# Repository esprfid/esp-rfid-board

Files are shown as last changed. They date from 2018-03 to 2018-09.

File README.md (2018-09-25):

# ESP12 / ESP12F / ESP12E / ESP12S Wiegand rfid board

Small ESP12F breakout board, custom built for Wiegand RFID readers.

### You can get this board from my Tindie shop:
<a href="https://www.tindie.com/stores/nardev/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">

</a>

WARNING: Although it’s rated for more than 12V, i strongly suggest to use maximum of 12V input!

Check the image for explanation of how to hook up the reader

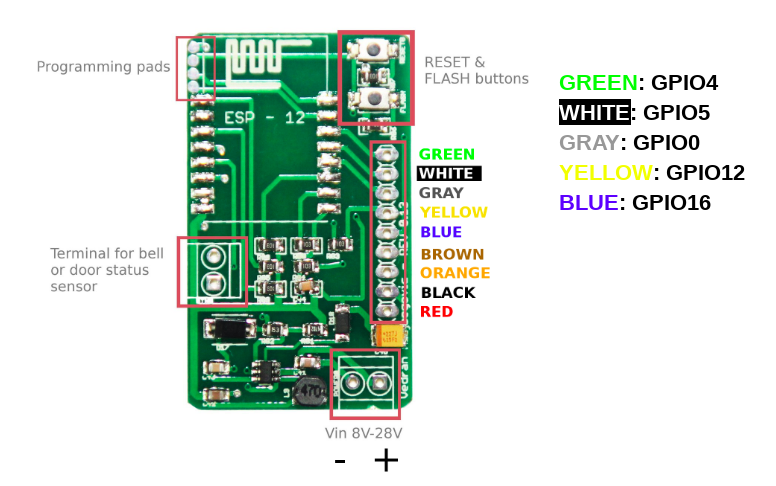
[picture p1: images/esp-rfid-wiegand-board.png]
&nbsp;&nbsp;

** There is a resistor on the way from ESP to buzzer due to strange behaviour of busser that ditn't react to HIGN/LOW except if there is a resitor on the way from ESP to Wiegand reader.

Custom pads

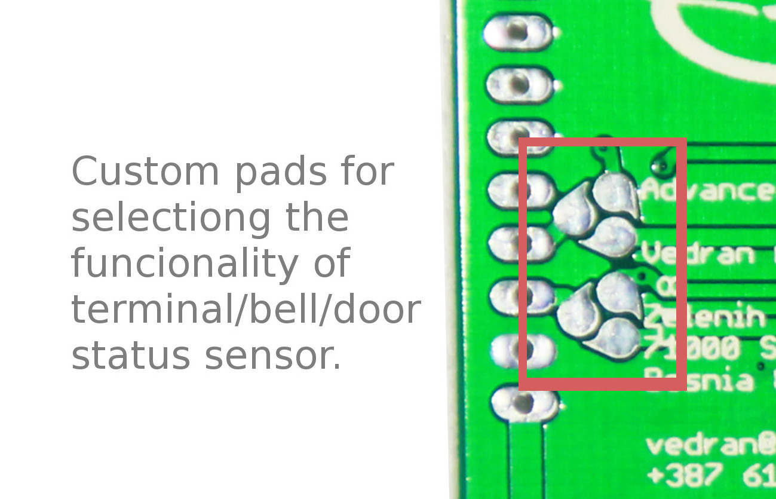
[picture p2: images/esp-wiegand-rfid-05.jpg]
&nbsp;&nbsp;
<br>
** New board has marked pads

**Option 1:**
Solder 2 and 1 on both pads results in passing “Ring” tactile switch/button to ESP8266 pin GPIO14

**Option 2:**
Solder 3 and 2 on both pads results in passing “Ring” switch to a terminal on  another side of board.

**Option 3:**
Solder 1 and 3 on both pads results in passing terminal pins to ESP8266 GPIO14, planned so that you can hook door status magnet sensor. In this case, you can’t use “Ring” button in Option 1. or 2.

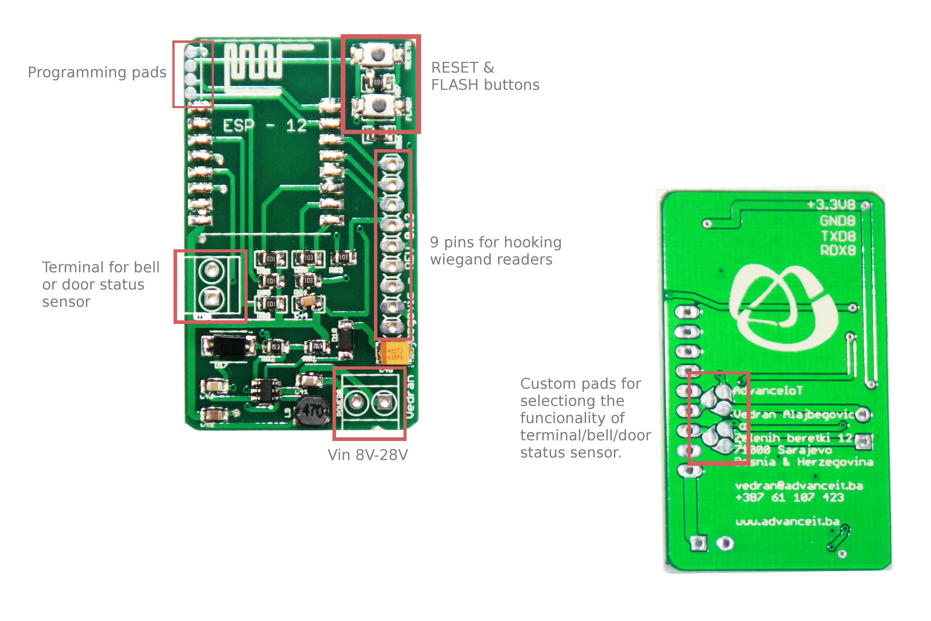
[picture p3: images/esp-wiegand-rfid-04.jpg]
&nbsp;&nbsp;

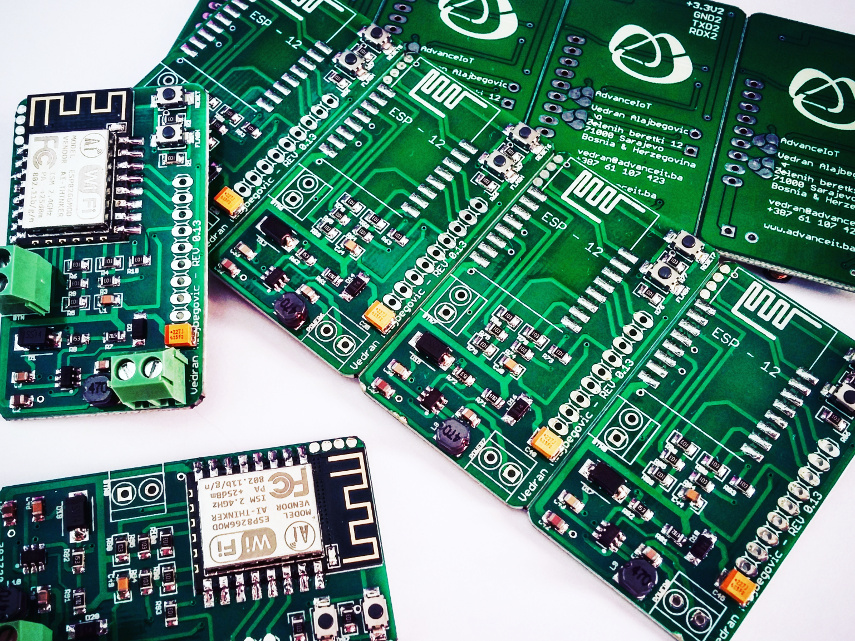
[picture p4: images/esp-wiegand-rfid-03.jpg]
&nbsp;&nbsp;
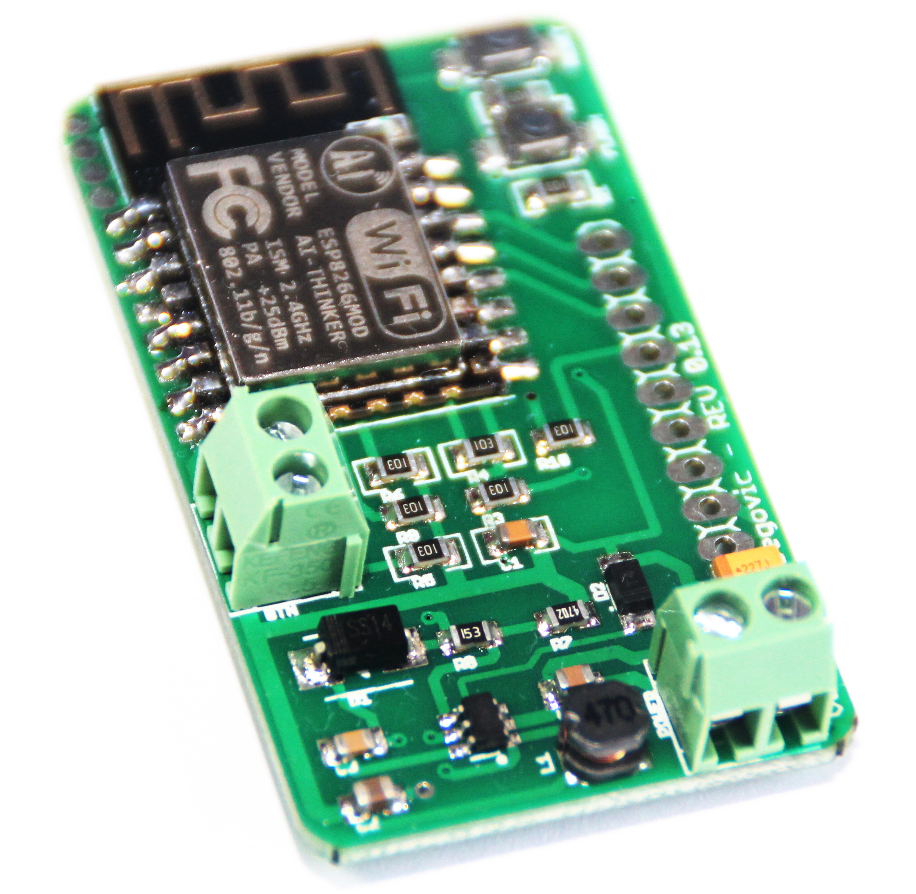
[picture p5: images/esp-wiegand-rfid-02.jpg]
&nbsp;&nbsp;
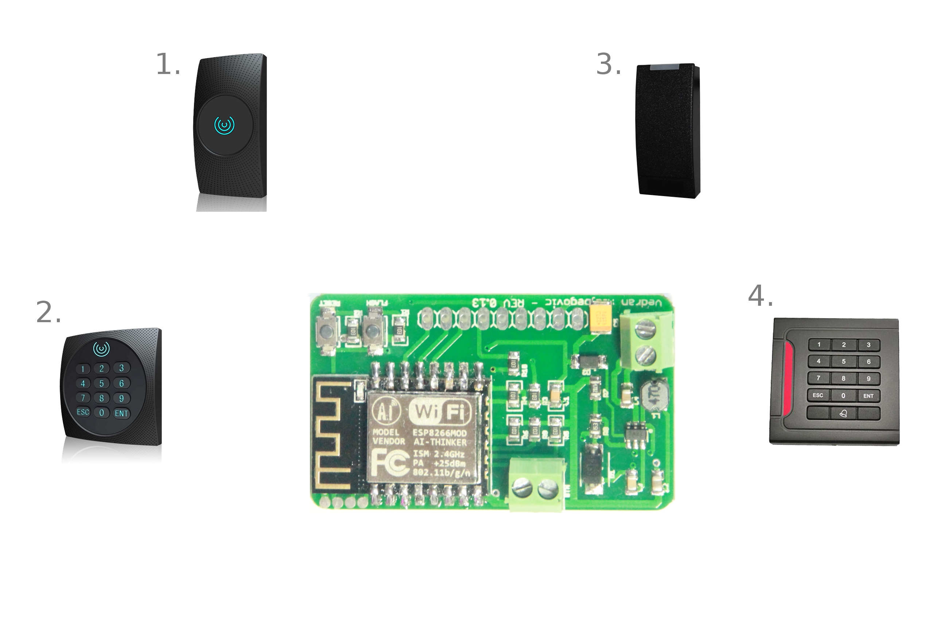
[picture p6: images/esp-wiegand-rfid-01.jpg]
&nbsp;&nbsp;

* BOM has some mistakes, contact me if you need some help.

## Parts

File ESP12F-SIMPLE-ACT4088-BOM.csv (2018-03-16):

Part | Value | Device | Package | Description
BTN | GTN | SCREW-TERMINAL-GREEN(2P-3.5) | H2-3.5-7.0X7.0MM | 320110028
BUCKCONV | AIC1896CG-SOT23-6 | ACT4088-(SOT23-6) | SOT-23-6 | 310030104
C1 | 100n | CAPC0805 | C_0805
C2 | 22uF | C-EUC0805K | C0805K | CAPACITOR, European symbol
C3 | 22nF | C-EUC0805K | C0805K | CAPACITOR, European symbol
C4 | 10uF | C-EUC0805K | C0805K | CAPACITOR, European symbol
C5 | 220uF | CAPC1411 | 1411/3528 | CAPACITOR 6.3V/220UF
D1 |  | SCHOTTKY-DIODESMD | SMB | Schottky Diode
D2 | LL4148 | LL4148 | SOD80_DO213AA_MINIMELF | 1N4148 General Purpose Rectifie
F1 |  | SJ2W | SJ_2 | SMD solder JUMPER
F2 |  | SJ2W | SJ_2 | SMD solder JUMPER
L1 | 4.7uH | L-EUL3225M | L3225M | INDUCTOR, European symbol
PINOUT |  | PINHD-1X9 | 1X09 | PIN HEADER
POWER | BTN | SCREW-TERMINAL-GREEN(2P-3.5) | H2-3.5-7.0X7.0MM | 320110028
R1 | 10K | RESISTORR0805 | R_0805
R2 | 10K | RESISTORR0805 | R_0805
R3 | 10K | R-EU_R0805 | R0805 | RESISTOR, European symbol
R4 | 10K | RESISTORR0805 | R_0805
R5 | 10K | RESISTORR0805 | R_0805
R6 | 10K | RESISTORR0805 | R_0805
R7 | 49.9K | R-EU_R0805 | R0805 | RESISTOR, European symbol
R8 | 16.2K | R-EU_R0805 | R0805 | RESISTOR, European symbol
R9 | 10K | R-EU_R0805 | R0805 | RESISTOR, European symbol
R10 | 10K | R-EU_R0805 | R0805 | RESISTOR, European symbol
RESET |  | BUTTON-2PSWITCH-TURTLE-2P | 2P-SWITCH-TURTLE
SW1 | FLASH | BUTTON-2PSWITCH-TURTLE-2P | 2P-SWITCH-TURTLE
TP1 | TPTP15R | TPTP15R | TP15R | Test pad
TP2 | TPTP15R | TPTP15R | TP15R | Test pad
TP3 | TPTP15R | TPTP15R | TP15R | Test pad
TP4 | TPTP15R | TPTP15R | TP15R | Test pad
U1 |  | ESP12SMD | ESP12-SMD | ESP8266 Wifi module 12

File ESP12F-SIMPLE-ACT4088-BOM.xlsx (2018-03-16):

NUMBER | Part | Value | Device | Package | Description
1 | BTN |  | SCREW-TERMINAL-GREEN(2P-3.5) | H2-3.5-7.0X7.0MM
1 | BUCKCONV | AIC1896CG-SOT23-6 | ACT4088-(SOT23-6) | SOT23-6 | I think that you can get those at: https://world.tmall.com/item/525197822499.htm?id=525197822499&ns=1&abbucket=18
1 | C1 | 100n | CAPC0805 | C0805K
2 | C2 | 22uF | CAPC0805 | C0805K | CAPACITOR, European symbol
x | C3 | 22nF | CAPC0805 | C0805K | CAPACITOR, European symbol
1 | C4 | 10uF | CAPC0805 | C0805K | CAPACITOR, European symbol
 | C5 | 220uF | CAPC1411 | 1411/3528 | CAPACITOR 6.3V/220UF
1 | D1 |  | SCHOTTKY-DIODESMD-SSB44-E3/52T | SMB | Schottky Diode, this one or similar: https://world.taobao.com/item/530833486252.htm?spm=a312a.7700714.0.0.7df3e12cR9cpXS#detail
1 | D2 | LL4148 | 1N4148 | SOD80_DO213AA_MINIMELF | 1N4148 General Purpose Rectifie, If you can’t get this one, you can skip it for demo board. I don’t know if this one is right size: https://world.tmall.com/item/14037506268.htm?id=14037506268&ali_trackid=1_09a98b3ccd918b57bda5394b2578982a
 | F1 |  | SJ2W | SJ_2 | SMD solder JUMPER
 | F2 |  | SJ2W | SJ_2 | SMD solder JUMPER
1 | L1 | 4.7uH | L-EUL3225M | L3225M | Inductor OR SAME VALUE, SAME PADS another one… Maybe this one: https://world.tmall.com/item/558066240065.htm?spm=a312a.7700714.0.0.2c8e0dba3eIeay
 | PINOUT |  | PINHD-1X9 | 1X09 | PIN HEADER
1 | POWER |  | SCREW-TERMINAL-GREEN(2P-3.5) | H2-3.5-7.0X7.0MM
8 | R1 | 10K | RESISTORR0805 | R0805
x | R2 | 10K | RESISTORR0805 | R0805
x | R3 | 10K | RESISTORR0805 | R0805
x | R4 | 10K | RESISTORR0805 | R0805
x | R5 | 10K | RESISTORR0805 | R0805
x | R6 | 10K | RESISTORR0805 | R0805
1 | R7 | 49.9K | RESISTORR0805 | R0805 | RESISTOR, European symbol
1 | R8 | 16.2K | RESISTORR0805 | R0805 | RESISTOR, European symbol
x | R9 | 10K | RESISTORR0805 | R0805 | RESISTOR, European symbol
x | R10 | 10K | RESISTORR0805 | R0805 | RESISTOR, European symbol
2 | RESET | RESET | BUTTON-2PSWITCH-TURTLE-2P | 2P-SWITCH-TURTLE
x | FLASH | FLASH | BUTTON-2PSWITCH-TURTLE-2P | 2P-SWITCH-TURTLE
 | GND | TPTP15R | TPTP15R | TP15R | Test pad
 | TXD | TPTP15R | TPTP15R | TP15R | Test pad
 | RXD | TPTP15R | TPTP15R | TP15R | Test pad
 | +3.3V | TPTP15R | TPTP15R | TP15R | Test pad
1 | MCU |  | ESP12SMD | ESP12-SMD | ESP12F - 8266 Wifi module 12
11
2 |  | SKIP PARTS WITH THIS BACKGROUND COLOR
13 |  | Read the description

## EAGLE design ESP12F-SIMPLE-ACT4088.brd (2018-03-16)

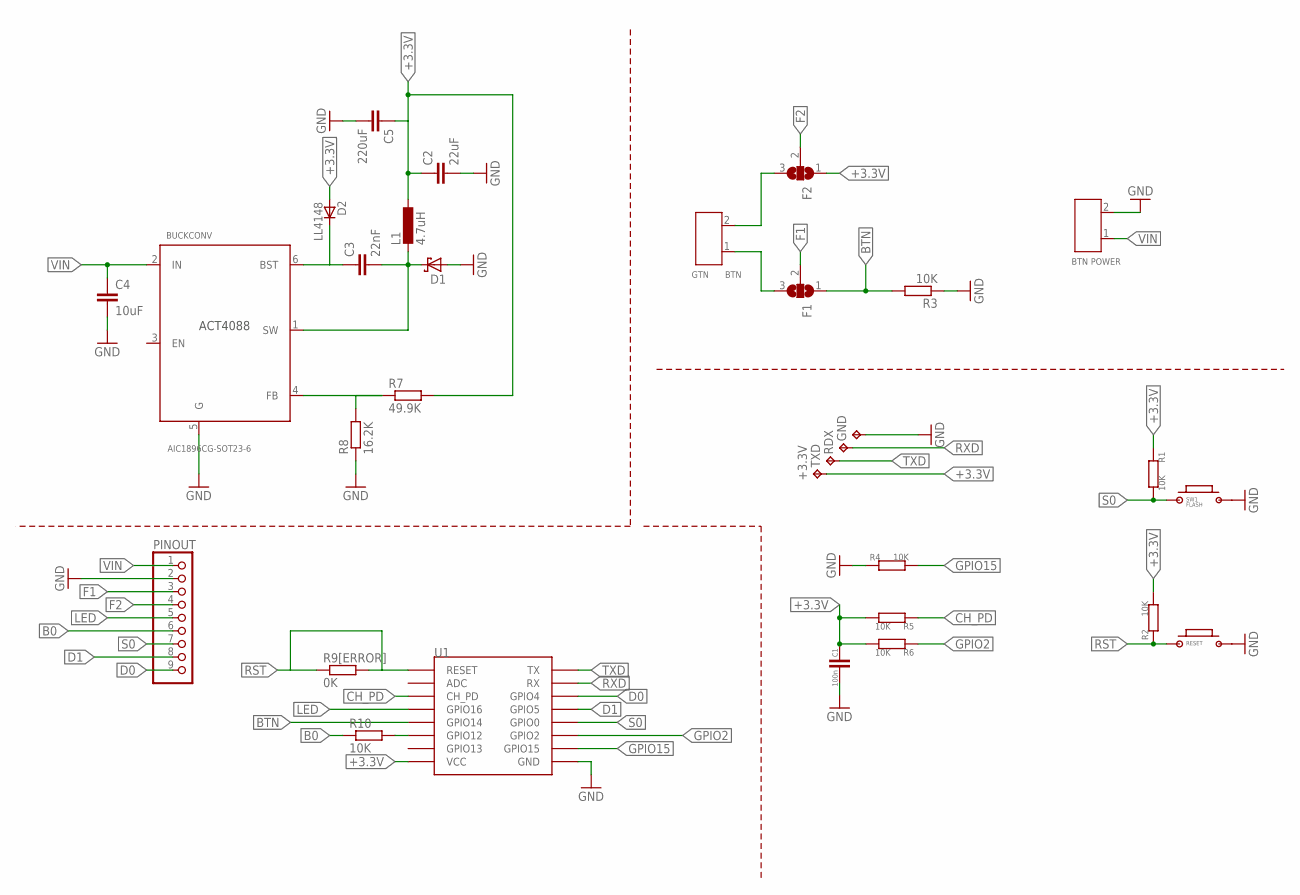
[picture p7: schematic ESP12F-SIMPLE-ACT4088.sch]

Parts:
+3.3V: TPTP15R; TP15R
BTN: GTN; H2-3.5-7.0X7.0MM
BUCKCONV: AIC1896CG-SOT23-6; SOT-23-6
C1: 100n; C_0805
C2: 22uF; C0805K
C3: 22nF; C0805K
C4: 10uF; C0805K
C5: 220uF; C1210
D1: SCHOTTKY-DIODESMD; SMB
D2: LL4148; SOD80_DO213AA_MINIMELF
F1, F2: SJ2WX; SJ_2XX
GND: TPTP15R; TP15R
L1: 4.7uH; L3225M
PINOUT: PINHD-1X9; 1X09
POWER: BTN; H2-3.5-7.0X7.0MM
R1, R2, R4, R5, R6: 10K; R_0805
R3, R10: 10K; R0805
R7: 49.9K; R0805
R8: 16.2K; R0805
R9[ERROR]: 0K; R0805
RDX: TPTP15R; TP15R
RESET: BUTTON-2PSWITCH-TURTLE-2P; 2P-SWITCH-TURTLE
SW1: FLASH; 2P-SWITCH-TURTLE
TXD: TPTP15R; TP15R
U1: ESP12SMD; ESP12-SMD

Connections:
+3.3V: +3.3V.TP, C1.1, C2.1, C5.1, D2.A, F2.1, L1.1, R1.1, R2.2, R5.2, R6.2, R7.2, U1.VCC
B0: PINOUT.6, R10.1
BTN: F1.1, R3.2, U1.GPIO14
CH_PD: R5.1, U1.CH_PD
D0: PINOUT.9, U1.GPIO4
D1: PINOUT.8, U1.GPIO5
F1: F1.2, PINOUT.3
F2: F2.2, PINOUT.4
GND: BUCKCONV.5 (G), C1.2, C2.2, C4.2, C5.2, D1.A, GND.TP, PINOUT.2, POWER.2, R3.1, R4.1, R8.1, RESET.2, SW1.2, U1.GND
GPIO2: R6.1, U1.GPIO2
GPIO15: R4.2, U1.GPIO15
LED: PINOUT.5, U1.GPIO16
unnamed: BUCKCONV.1 (SW), C3.2, D1.C, L1.2
unnamed: R10.2, U1.GPIO12
unnamed: BUCKCONV.6 (BST), C3.1, D2.C
unnamed: BUCKCONV.4 (FB), R7.1, R8.2
unnamed: BTN.1, F1.3
unnamed: BTN.2, F2.3
RST: R2.1, R9[ERROR].1, R9[ERROR].2, RESET.1, U1.RESET
RXD: RDX.TP, U1.RXD0 (RX)
S0: PINOUT.7, R1.2, SW1.1, U1.GPIO0
TXD: TXD.TP, U1.TXD0 (TX)
VIN: BUCKCONV.2 (IN), C4.1, PINOUT.1, POWER.1

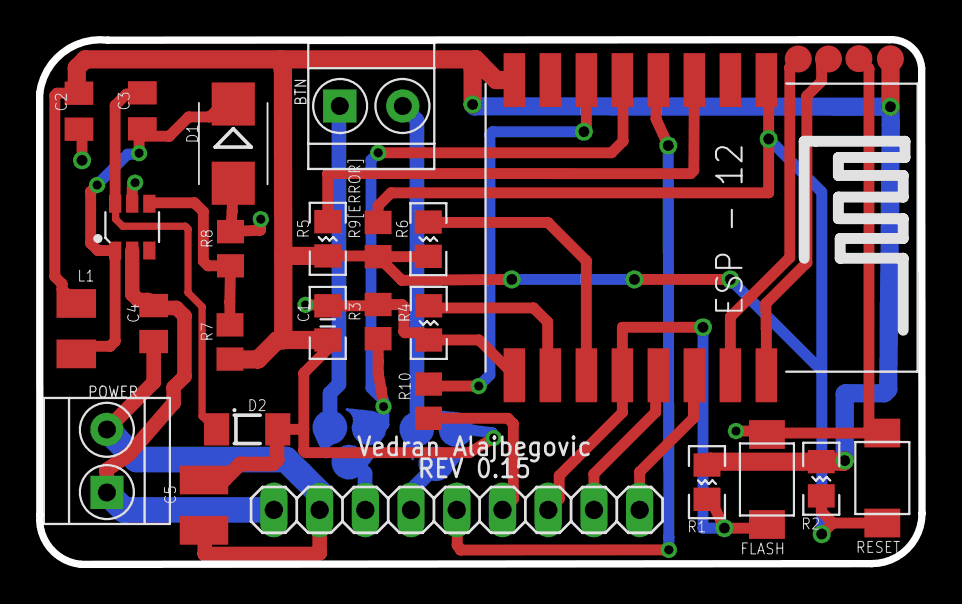
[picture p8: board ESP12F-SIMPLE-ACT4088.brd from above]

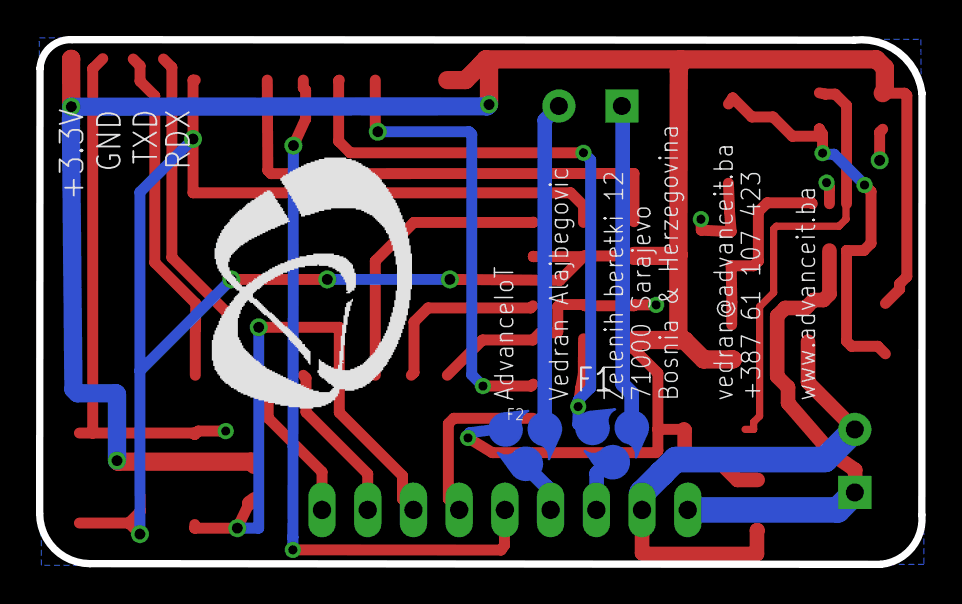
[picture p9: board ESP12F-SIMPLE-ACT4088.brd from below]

Board: 2 copper layers, 49.0 x 29.1 mm, 31 parts (2 on the bottom side), 23 nets.

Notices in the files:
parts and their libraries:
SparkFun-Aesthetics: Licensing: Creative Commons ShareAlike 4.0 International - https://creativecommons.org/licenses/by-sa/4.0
